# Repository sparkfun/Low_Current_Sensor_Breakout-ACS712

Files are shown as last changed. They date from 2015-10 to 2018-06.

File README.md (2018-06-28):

**NOTE:** *This product has been retired from our catalog. There is an updated drop-in replacement with the ACS723 available: [SEN-14544](https://github.com/sparkfun/Current_Sensor_Breakout-ACS723-Low_Current). If you are looking for more up-to-date info, please check out some of these resources to see how other users are still hacking and improving on this product version.*

* *[SparkFun Forum](https://forum.sparkfun.com/)*
* *[Comments Here on GitHub](https://github.com/sparkfun/Low_Current_Sensor_Breakout-ACS712/issues)*
* *[IRC Channel](https://www.sparkfun.com/news/263)*

SparkFun Low Current Sensor Breakout Board - ACS712
======================================================

SparkFun Low Current Sensor Breakout Board - ACS712

[*SparkFun Low Current Sensor Breakout Board - ACS712 (SEN-08883)*](https://www.sparkfun.com/products/8883) 

This current sensor gives precise current measurement for both AC and DC signals. 
These are good sensors for metering and measuring overall power consumption of systems.
The ACS712 Low Current Sensor Breakout outputs an analog voltage that varies linearly with sensed current.

Repository Contents
-------------------
* **/Hardware** - All Eagle design files (.brd, .sch)

Documentation
--------------
* **[Hookup Guide](https://learn.sparkfun.com/tutorials/acs712-low-current-sensor-hookup-guide)** - Basic hookup guide for the ACS712.

Product Versions
----------------

* [SEN-08883 (RETIRED)](https://www.sparkfun.com/products/8883)- Initial release; ACS712 Version of this Board

License Information
-------------------

This product is _**open source**_! 

Please review the LICENSE.md file for license information. 

If you have any questions or concerns on licensing, please contact techsupport@sparkfun.com.

Distributed as-is; no warranty is given.

- Your friends at SparkFun.

_<COLLABORATION CREDIT>_

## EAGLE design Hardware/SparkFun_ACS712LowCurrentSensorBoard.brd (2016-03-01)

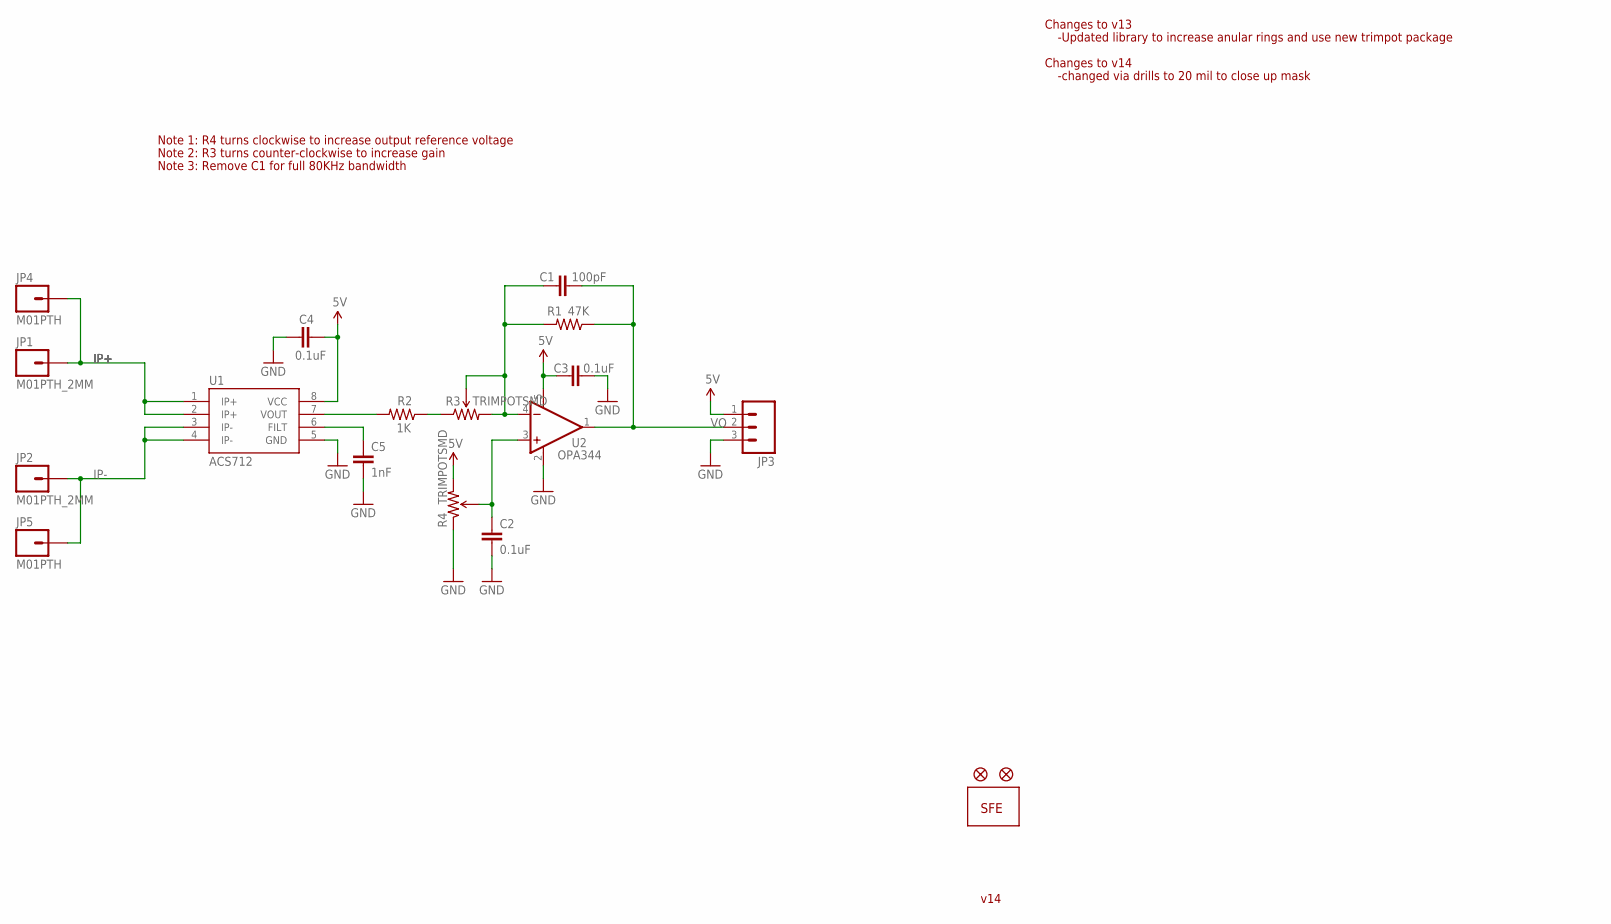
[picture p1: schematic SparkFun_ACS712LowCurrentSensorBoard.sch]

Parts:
C1: 100pF; 0402-CAP
C2, C3, C4: 0.1uF; 0402-CAP
C5: 1nF; 0402-CAP
JP1, JP2: M01PTH_2MM; 1X01_2MM
JP3: M03PTH; 1X03
JP4, JP5: M01PTH; 1X01
R1: 47K; 0402-RES
R2: 1K; 0402-RES
R3, R4: TRIMPOTSMD; TRIMPOT-3MM
U1: ACS712; SO08
U2: OPA344; SOT23-5
U$1, U$3: FIDUCIALUFIDUCIAL; MICRO-FIDUCIAL
U$2: LOGO-SFENEW; SFE-NEW-WEBLOGO

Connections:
5V: C3.1, C4.2, JP3.1, R4.3 (CW), U1.8 (VCC), U2.5 (V+)
GND: C2.2, C3.2, C4.1, C5.2, JP3.3, R4.1 (CCW), U1.5 (GND), U2.2 (V-)
IP+: JP1.1, JP4.1, U1.1 (IP+), U1.2 (IP+)
IP-: JP2.1, JP5.1, U1.3 (IP-), U1.4 (IP-)
unnamed: R2.2, U1.7 (VOUT)
unnamed: R2.1, R3.1 (CCW)
unnamed: C1.2, R1.2, R3.2 (WIPER), R3.3 (CW), U2.4 (-IN)
unnamed: C2.1, R4.2 (WIPER), U2.3 (+IN)
unnamed: C5.1, U1.6 (FILT)
VO: C1.1, JP3.2, R1.1, U2.1 (OUT)

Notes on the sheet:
Note 1: R4 turns clockwise to increase output reference voltage
Note 2: R3 turns counter-clockwise to increase gain
Note 3: Remove C1 for full 80KHz bandwidth
Changes to v13
-Updated library to increase anular rings and use new trimpot package
Changes to v14
-changed via drills to 20 mil to close up mask
v14

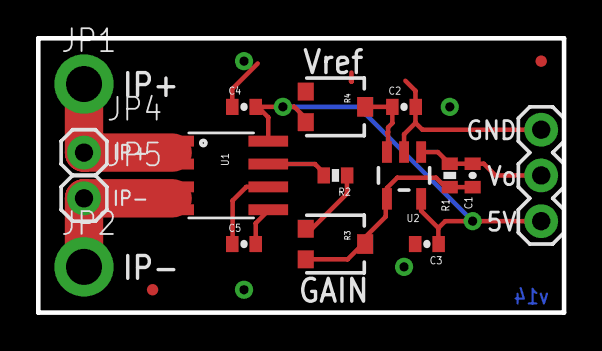
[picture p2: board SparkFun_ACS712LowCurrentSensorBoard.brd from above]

Board: 2 copper layers, 29.2 x 15.2 mm, 19 parts (1 on the bottom side), 10 nets.

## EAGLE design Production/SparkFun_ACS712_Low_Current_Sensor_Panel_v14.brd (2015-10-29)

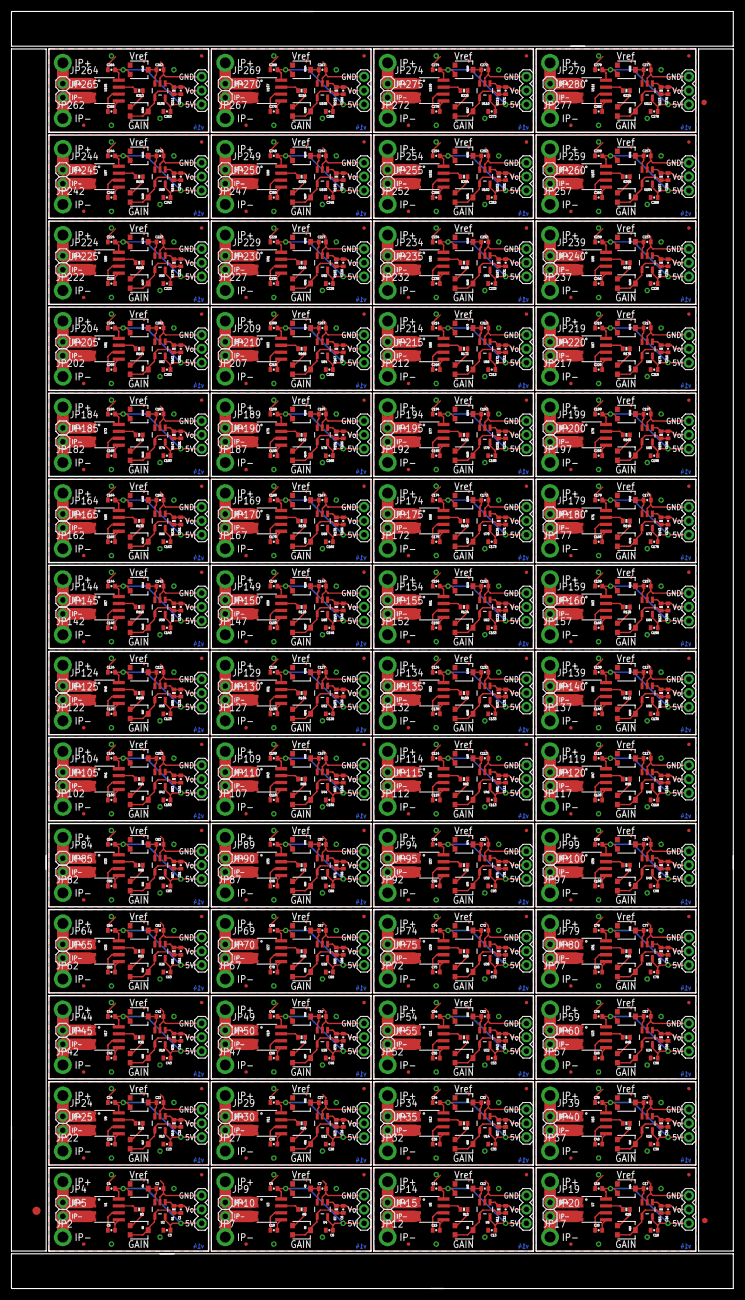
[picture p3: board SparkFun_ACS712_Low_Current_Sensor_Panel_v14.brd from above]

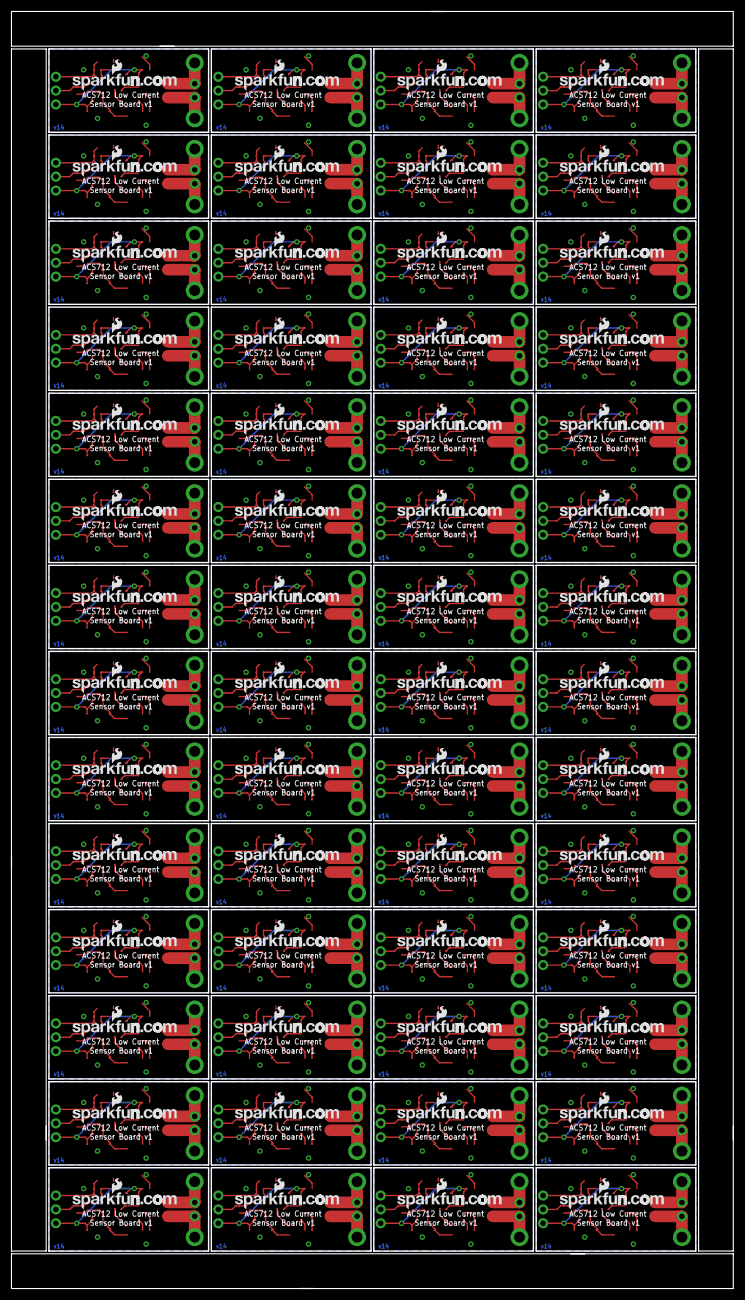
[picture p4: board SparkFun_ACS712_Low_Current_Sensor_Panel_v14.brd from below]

Board: 2 copper layers, 132.1 x 233.7 mm, 1067 parts (56 on the bottom side), 560 nets.

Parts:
C1, C2, C3, C4, C6, C7, C8, C9, C11, C12, C13, C14, C16, C17, C18, C19, C21, C22, C23, C24, C26, C27, C28, C29, C31, C32, C33, C34, C36, C37, C38, C39, C41, C42, C43, C44, C46, C47, C48, C49, C51, C52, C53, C54, C56, C57, C58, C59, C61, C62, C63, C64, C66, C67, C68, C69, C71, C72, C73, C74, C76, C77, C78, C79, C81, C82, C83, C84, C86, C87, C88, C89, C91, C92, C93, C94, C96, C97, C98, C99, C101, C102, C103, C104, C106, C107, C108, C109, C111, C112, C113, C114, C116, C117, C118, C119, C121, C122, C123, C124, C126, C127, C128, C129, C131, C132, C133, C134, C136, C137, C138, C139, C141, C142, C143, C144, C146, C147, C148, C149, C151, C152, C153, C154, C156, C157, C158, C159, C161, C162, C163, C164, C166, C167, C168, C169, C171, C172, C173, C174, C176, C177, C178, C179, C181, C182, C183, C184, C186, C187, C188, C189, C191, C192, C193, C194, C196, C197, C198, C199, C201, C202, C203, C204, C206, C207, C208, C209, C211, C212, C213, C214, C216, C217, C218, C219, C221, C222, C223, C224, C226, C227, C228, C229, C231, C232, C233, C234, C236, C237, C238, C239, C241, C242, C243, C244, C246, C247, C248, C249, C251, C252, C253, C254, C256, C257, C258, C259, C261, C262, C263, C264, C266, C267, C268, C269, C271, C272, C273, C274, C276, C277, C278, C279: 0.1uF; 0402-CAP
C5, C10, C15, C20, C25, C30, C35, C40, C45, C50, C55, C60, C65, C70, C75, C80, C85, C90, C95, C100, C105, C110, C115, C120, C125, C130, C135, C140, C145, C150, C155, C160, C165, C170, C175, C180, C185, C190, C195, C200, C205, C210, C215, C220, C225, C230, C235, C240, C245, C250, C255, C260, C265, C270, C275, C280: 1nF; 0402-CAP
E$1: FIDUCIAL-1.5X3
E$5, E$7: FIDUCIAL-1X2
JP1, JP2, JP6, JP7, JP11, JP12, JP16, JP17, JP21, JP22, JP26, JP27, JP31, JP32, JP36, JP37, JP41, JP42, JP46, JP47, JP51, JP52, JP56, JP57, JP61, JP62, JP66, JP67, JP71, JP72, JP76, JP77, JP81, JP82, JP86, JP87, JP91, JP92, JP96, JP97, JP101, JP102, JP106, JP107, JP111, JP112, JP116, JP117, JP121, JP122, JP126, JP127, JP131, JP132, JP136, JP137, JP141, JP142, JP146, JP147, JP151, JP152, JP156, JP157, JP161, JP162, JP166, JP167, JP171, JP172, JP176, JP177, JP181, JP182, JP186, JP187, JP191, JP192, JP196, JP197, JP201, JP202, JP206, JP207, JP211, JP212, JP216, JP217, JP221, JP222, JP226, JP227, JP231, JP232, JP236, JP237, JP241, JP242, JP246, JP247, JP251, JP252, JP256, JP257, JP261, JP262, JP266, JP267, JP271, JP272, JP276, JP277: M01PTH_2MM; 1X01_2MM
JP3, JP8, JP13, JP18, JP23, JP28, JP33, JP38, JP43, JP48, JP53, JP58, JP63, JP68, JP73, JP78, JP83, JP88, JP93, JP98, JP103, JP108, JP113, JP118, JP123, JP128, JP133, JP138, JP143, JP148, JP153, JP158, JP163, JP168, JP173, JP178, JP183, JP188, JP193, JP198, JP203, JP208, JP213, JP218, JP223, JP228, JP233, JP238, JP243, JP248, JP253, JP258, JP263, JP268, JP273, JP278: 1X03
JP4, JP5, JP9, JP10, JP14, JP15, JP19, JP20, JP24, JP25, JP29, JP30, JP34, JP35, JP39, JP40, JP44, JP45, JP49, JP50, JP54, JP55, JP59, JP60, JP64, JP65, JP69, JP70, JP74, JP75, JP79, JP80, JP84, JP85, JP89, JP90, JP94, JP95, JP99, JP100, JP104, JP105, JP109, JP110, JP114, JP115, JP119, JP120, JP124, JP125, JP129, JP130, JP134, JP135, JP139, JP140, JP144, JP145, JP149, JP150, JP154, JP155, JP159, JP160, JP164, JP165, JP169, JP170, JP174, JP175, JP179, JP180, JP184, JP185, JP189, JP190, JP194, JP195, JP199, JP200, JP204, JP205, JP209, JP210, JP214, JP215, JP219, JP220, JP224, JP225, JP229, JP230, JP234, JP235, JP239, JP240, JP244, JP245, JP249, JP250, JP254, JP255, JP259, JP260, JP264, JP265, JP269, JP270, JP274, JP275, JP279, JP280: M01PTH; 1X01
R1, R7, R11, R15, R19, R23, R27, R31, R35, R39, R43, R47, R51, R55, R59, R63, R67, R71, R75, R79, R83, R87, R91, R95, R99, R103, R107, R111, R115, R119, R123, R127, R131, R135, R139, R143, R147, R151, R155, R159, R163, R167, R171, R175, R179, R183, R187, R191, R195, R199, R203, R207, R211, R215, R219, R223: 47K; 0402-RES
R2, R8, R12, R16, R20, R24, R28, R32, R36, R40, R44, R48, R52, R56, R60, R64, R68, R72, R76, R80, R84, R88, R92, R96, R100, R104, R108, R112, R116, R120, R124, R128, R132, R136, R140, R144, R148, R152, R156, R160, R164, R168, R172, R176, R180, R184, R188, R192, R196, R200, R204, R208, R212, R216, R220, R224: 1K; 0402-RES
R3, R4, R5, R6, R9, R10, R13, R14, R17, R18, R21, R22, R25, R26, R29, R30, R33, R34, R37, R38, R41, R42, R45, R46, R49, R50, R53, R54, R57, R58, R61, R62, R65, R66, R69, R70, R73, R74, R77, R78, R81, R82, R85, R86, R89, R90, R93, R94, R97, R98, R101, R102, R105, R106, R109, R110, R113, R114, R117, R118, R121, R122, R125, R126, R129, R130, R133, R134, R137, R138, R141, R142, R145, R146, R149, R150, R153, R154, R157, R158, R161, R162, R165, R166, R169, R170, R173, R174, R177, R178, R181, R182, R185, R186, R189, R190, R193, R194, R197, R198, R201, R202, R205, R206, R209, R210, R213, R214, R217, R218, R221, R222: TRIMPOTSMD; TRIMPOT-3MM
U1, U3, U5, U7, U9, U11, U13, U15, U17, U19, U21, U23, U25, U27, U29, U31, U33, U35, U37, U39, U41, U43, U45, U47, U49, U51, U53, U55, U57, U59, U61, U63, U65, U67, U69, U71, U73, U75, U77, U79, U81, U83, U85, U87, U89, U91, U93, U95, U97, U99, U101, U103, U105, U107, U109, U111: ACS712; SO08
U2, U4, U6, U8, U10, U12, U14, U16, U18, U20, U22, U24, U26, U28, U30, U32, U34, U36, U38, U40, U42, U44, U46, U48, U50, U52, U54, U56, U58, U60, U62, U64, U66, U68, U70, U72, U74, U76, U78, U80, U82, U84, U86, U88, U90, U92, U94, U96, U98, U100, U102, U104, U106, U108, U110, U112: OPA344; SOT23-5
U$1, U$3, U$5, U$6, U$8, U$9, U$11, U$12, U$14, U$15, U$17, U$18, U$20, U$21, U$23, U$24, U$26, U$27, U$29, U$30, U$32, U$33, U$35, U$36, U$38, U$39, U$41, U$42, U$44, U$45, U$47, U$48, U$50, U$51, U$53, U$54, U$56, U$57, U$59, U$60, U$62, U$63, U$65, U$66, U$68, U$69, U$71, U$72, U$74, U$75, U$77, U$78, U$80, U$81, U$83, U$84, U$86, U$87, U$89, U$90, U$92, U$93, U$95, U$96, U$98, U$99, U$101, U$102, U$104, U$105, U$107, U$108, U$110, U$111, U$113, U$114, U$116, U$117, U$119, U$120, U$122, U$123, U$125, U$126, U$128, U$129, U$131, U$132, U$134, U$135, U$137, U$138, U$140, U$141, U$143, U$144, U$146, U$147, U$149, U$150, U$152, U$153, U$155, U$156, U$158, U$159, U$161, U$162, U$164, U$165, U$167, U$168: FIDUCIALUFIDUCIAL; MICRO-FIDUCIAL
U$2, U$4, U$7, U$10, U$13, U$16, U$19, U$22, U$25, U$28, U$31, U$34, U$37, U$40, U$43, U$46, U$49, U$52, U$55, U$58, U$61, U$64, U$67, U$70, U$73, U$76, U$79, U$82, U$85, U$88, U$91, U$94, U$97, U$100, U$103, U$106, U$109, U$112, U$115, U$118, U$121, U$124, U$127, U$130, U$133, U$136, U$139, U$142, U$145, U$148, U$151, U$154, U$157, U$160, U$163, U$166: LOGO-SFENEW; SFE-NEW-WEBLOGO

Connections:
5V: C3.1, C4.2, JP3.1, R4.3, U1.8, U2.5
5V1: C8.1, C9.2, JP8.1, R6.3, U3.8, U4.5
5V2: C13.1, C14.2, JP13.1, R10.3, U5.8, U6.5
5V3: C18.1, C19.2, JP18.1, R14.3, U7.8, U8.5
5V4: C23.1, C24.2, JP23.1, R18.3, U9.8, U10.5
5V5: C28.1, C29.2, JP28.1, R22.3, U11.8, U12.5
5V6: C33.1, C34.2, JP33.1, R26.3, U13.8, U14.5
5V7: C38.1, C39.2, JP38.1, R30.3, U15.8, U16.5
5V8: C43.1, C44.2, JP43.1, R34.3, U17.8, U18.5
5V9: C48.1, C49.2, JP48.1, R38.3, U19.8, U20.5
5V10: C53.1, C54.2, JP53.1, R42.3, U21.8, U22.5
5V11: C58.1, C59.2, JP58.1, R46.3, U23.8, U24.5
5V12: C63.1, C64.2, JP63.1, R50.3, U25.8, U26.5
5V13: C68.1, C69.2, JP68.1, R54.3, U27.8, U28.5
5V14: C73.1, C74.2, JP73.1, R58.3, U29.8, U30.5
5V15: C78.1, C79.2, JP78.1, R62.3, U31.8, U32.5
5V16: C83.1, C84.2, JP83.1, R66.3, U33.8, U34.5
5V17: C88.1, C89.2, JP88.1, R70.3, U35.8, U36.5
5V18: C93.1, C94.2, JP93.1, R74.3, U37.8, U38.5
5V19: C98.1, C99.2, JP98.1, R78.3, U39.8, U40.5
5V20: C103.1, C104.2, JP103.1, R82.3, U41.8, U42.5
5V21: C108.1, C109.2, JP108.1, R86.3, U43.8, U44.5
5V22: C113.1, C114.2, JP113.1, R90.3, U45.8, U46.5
5V23: C118.1, C119.2, JP118.1, R94.3, U47.8, U48.5
5V24: C123.1, C124.2, JP123.1, R98.3, U49.8, U50.5
5V25: C128.1, C129.2, JP128.1, R102.3, U51.8, U52.5
5V26: C133.1, C134.2, JP133.1, R106.3, U53.8, U54.5
5V27: C138.1, C139.2, JP138.1, R110.3, U55.8, U56.5
5V28: C143.1, C144.2, JP143.1, R114.3, U57.8, U58.5
5V29: C148.1, C149.2, JP148.1, R118.3, U59.8, U60.5
5V30: C153.1, C154.2, JP153.1, R122.3, U61.8, U62.5
5V31: C158.1, C159.2, JP158.1, R126.3, U63.8, U64.5
5V32: C163.1, C164.2, JP163.1, R130.3, U65.8, U66.5
5V33: C168.1, C169.2, JP168.1, R134.3, U67.8, U68.5
5V34: C173.1, C174.2, JP173.1, R138.3, U69.8, U70.5
5V35: C178.1, C179.2, JP178.1, R142.3, U71.8, U72.5
5V36: C183.1, C184.2, JP183.1, R146.3, U73.8, U74.5
5V37: C188.1, C189.2, JP188.1, R150.3, U75.8, U76.5
5V38: C193.1, C194.2, JP193.1, R154.3, U77.8, U78.5
5V39: C198.1, C199.2, JP198.1, R158.3, U79.8, U80.5
5V40: C203.1, C204.2, JP203.1, R162.3, U81.8, U82.5
5V41: C208.1, C209.2, JP208.1, R166.3, U83.8, U84.5
5V42: C213.1, C214.2, JP213.1, R170.3, U85.8, U86.5
5V43: C218.1, C219.2, JP218.1, R174.3, U87.8, U88.5
5V44: C223.1, C224.2, JP223.1, R178.3, U89.8, U90.5
5V45: C228.1, C229.2, JP228.1, R182.3, U91.8, U92.5
5V46: C233.1, C234.2, JP233.1, R186.3, U93.8, U94.5
5V47: C238.1, C239.2, JP238.1, R190.3, U95.8, U96.5
5V48: C243.1, C244.2, JP243.1, R194.3, U97.8, U98.5
5V49: C248.1, C249.2, JP248.1, R198.3, U99.8, U100.5
5V50: C253.1, C254.2, JP253.1, R202.3, U101.8, U102.5
5V51: C258.1, C259.2, JP258.1, R206.3, U103.8, U104.5
5V52: C263.1, C264.2, JP263.1, R210.3, U105.8, U106.5
5V53: C268.1, C269.2, JP268.1, R214.3, U107.8, U108.5
5V54: C273.1, C274.2, JP273.1, R218.3, U109.8, U110.5
5V55: C278.1, C279.2, JP278.1, R222.3, U111.8, U112.5
GND: C2.2, C3.2, C4.1, C5.2, JP3.3, R4.1, U1.5, U2.2
GND1: C7.2, C8.2, C9.1, C10.2, JP8.3, R6.1, U3.5, U4.2
GND2: C12.2, C13.2, C14.1, C15.2, JP13.3, R10.1, U5.5, U6.2
GND3: C17.2, C18.2, C19.1, C20.2, JP18.3, R14.1, U7.5, U8.2
GND4: C22.2, C23.2, C24.1, C25.2, JP23.3, R18.1, U9.5, U10.2
GND5: C27.2, C28.2, C29.1, C30.2, JP28.3, R22.1, U11.5, U12.2
GND6: C32.2, C33.2, C34.1, C35.2, JP33.3, R26.1, U13.5, U14.2
GND7: C37.2, C38.2, C39.1, C40.2, JP38.3, R30.1, U15.5, U16.2
GND8: C42.2, C43.2, C44.1, C45.2, JP43.3, R34.1, U17.5, U18.2
GND9: C47.2, C48.2, C49.1, C50.2, JP48.3, R38.1, U19.5, U20.2
GND10: C52.2, C53.2, C54.1, C55.2, JP53.3, R42.1, U21.5, U22.2
GND11: C57.2, C58.2, C59.1, C60.2, JP58.3, R46.1, U23.5, U24.2
GND12: C62.2, C63.2, C64.1, C65.2, JP63.3, R50.1, U25.5, U26.2
GND13: C67.2, C68.2, C69.1, C70.2, JP68.3, R54.1, U27.5, U28.2
GND14: C72.2, C73.2, C74.1, C75.2, JP73.3, R58.1, U29.5, U30.2
GND15: C77.2, C78.2, C79.1, C80.2, JP78.3, R62.1, U31.5, U32.2
GND16: C82.2, C83.2, C84.1, C85.2, JP83.3, R66.1, U33.5, U34.2
GND17: C87.2, C88.2, C89.1, C90.2, JP88.3, R70.1, U35.5, U36.2
GND18: C92.2, C93.2, C94.1, C95.2, JP93.3, R74.1, U37.5, U38.2
GND19: C97.2, C98.2, C99.1, C100.2, JP98.3, R78.1, U39.5, U40.2
GND20: C102.2, C103.2, C104.1, C105.2, JP103.3, R82.1, U41.5, U42.2
GND21: C107.2, C108.2, C109.1, C110.2, JP108.3, R86.1, U43.5, U44.2
GND22: C112.2, C113.2, C114.1, C115.2, JP113.3, R90.1, U45.5, U46.2
GND23: C117.2, C118.2, C119.1, C120.2, JP118.3, R94.1, U47.5, U48.2
GND24: C122.2, C123.2, C124.1, C125.2, JP123.3, R98.1, U49.5, U50.2
GND25: C127.2, C128.2, C129.1, C130.2, JP128.3, R102.1, U51.5, U52.2
GND26: C132.2, C133.2, C134.1, C135.2, JP133.3, R106.1, U53.5, U54.2
GND27: C137.2, C138.2, C139.1, C140.2, JP138.3, R110.1, U55.5, U56.2
GND28: C142.2, C143.2, C144.1, C145.2, JP143.3, R114.1, U57.5, U58.2
GND29: C147.2, C148.2, C149.1, C150.2, JP148.3, R118.1, U59.5, U60.2
GND30: C152.2, C153.2, C154.1, C155.2, JP153.3, R122.1, U61.5, U62.2
GND31: C157.2, C158.2, C159.1, C160.2, JP158.3, R126.1, U63.5, U64.2
GND32: C162.2, C163.2, C164.1, C165.2, JP163.3, R130.1, U65.5, U66.2
GND33: C167.2, C168.2, C169.1, C170.2, JP168.3, R134.1, U67.5, U68.2
GND34: C172.2, C173.2, C174.1, C175.2, JP173.3, R138.1, U69.5, U70.2
GND35: C177.2, C178.2, C179.1, C180.2, JP178.3, R142.1, U71.5, U72.2
GND36: C182.2, C183.2, C184.1, C185.2, JP183.3, R146.1, U73.5, U74.2
GND37: C187.2, C188.2, C189.1, C190.2, JP188.3, R150.1, U75.5, U76.2
GND38: C192.2, C193.2, C194.1, C195.2, JP193.3, R154.1, U77.5, U78.2
GND39: C197.2, C198.2, C199.1, C200.2, JP198.3, R158.1, U79.5, U80.2
GND40: C202.2, C203.2, C204.1, C205.2, JP203.3, R162.1, U81.5, U82.2
GND41: C207.2, C208.2, C209.1, C210.2, JP208.3, R166.1, U83.5, U84.2
GND42: C212.2, C213.2, C214.1, C215.2, JP213.3, R170.1, U85.5, U86.2
GND43: C217.2, C218.2, C219.1, C220.2, JP218.3, R174.1, U87.5, U88.2
GND44: C222.2, C223.2, C224.1, C225.2, JP223.3, R178.1, U89.5, U90.2
GND45: C227.2, C228.2, C229.1, C230.2, JP228.3, R182.1, U91.5, U92.2
GND46: C232.2, C233.2, C234.1, C235.2, JP233.3, R186.1, U93.5, U94.2
GND47: C237.2, C238.2, C239.1, C240.2, JP238.3, R190.1, U95.5, U96.2
GND48: C242.2, C243.2, C244.1, C245.2, JP243.3, R194.1, U97.5, U98.2
GND49: C247.2, C248.2, C249.1, C250.2, JP248.3, R198.1, U99.5, U100.2
GND50: C252.2, C253.2, C254.1, C255.2, JP253.3, R202.1, U101.5, U102.2
GND51: C257.2, C258.2, C259.1, C260.2, JP258.3, R206.1, U103.5, U104.2
GND52: C262.2, C263.2, C264.1, C265.2, JP263.3, R210.1, U105.5, U106.2
GND53: C267.2, C268.2, C269.1, C270.2, JP268.3, R214.1, U107.5, U108.2
GND54: C272.2, C273.2, C274.1, C275.2, JP273.3, R218.1, U109.5, U110.2
GND55: C277.2, C278.2, C279.1, C280.2, JP278.3, R222.1, U111.5, U112.2
IP+: JP1.1, JP4.1, U1.1, U1.2
IP+1: JP6.1, JP9.1, U3.1, U3.2
IP+2: JP11.1, JP14.1, U5.1, U5.2
IP+3: JP16.1, JP19.1, U7.1, U7.2
IP+4: JP21.1, JP24.1, U9.1, U9.2
IP+5: JP26.1, JP29.1, U11.1, U11.2
IP+6: JP31.1, JP34.1, U13.1, U13.2
IP+7: JP36.1, JP39.1, U15.1, U15.2
IP+8: JP41.1, JP44.1, U17.1, U17.2
IP+9: JP46.1, JP49.1, U19.1, U19.2
IP+10: JP51.1, JP54.1, U21.1, U21.2
IP+11: JP56.1, JP59.1, U23.1, U23.2
IP+12: JP61.1, JP64.1, U25.1, U25.2
IP+13: JP66.1, JP69.1, U27.1, U27.2
IP+14: JP71.1, JP74.1, U29.1, U29.2
IP+15: JP76.1, JP79.1, U31.1, U31.2
IP+16: JP81.1, JP84.1, U33.1, U33.2
IP+17: JP86.1, JP89.1, U35.1, U35.2
IP+18: JP91.1, JP94.1, U37.1, U37.2
IP+19: JP96.1, JP99.1, U39.1, U39.2
IP+20: JP101.1, JP104.1, U41.1, U41.2
IP+21: JP106.1, JP109.1, U43.1, U43.2
IP+22: JP111.1, JP114.1, U45.1, U45.2
IP+23: JP116.1, JP119.1, U47.1, U47.2
IP+24: JP121.1, JP124.1, U49.1, U49.2
IP+25: JP126.1, JP129.1, U51.1, U51.2
IP+26: JP131.1, JP134.1, U53.1, U53.2
IP+27: JP136.1, JP139.1, U55.1, U55.2
IP+28: JP141.1, JP144.1, U57.1, U57.2
IP+29: JP146.1, JP149.1, U59.1, U59.2
IP+30: JP151.1, JP154.1, U61.1, U61.2
IP+31: JP156.1, JP159.1, U63.1, U63.2
IP+32: JP161.1, JP164.1, U65.1, U65.2
IP+33: JP166.1, JP169.1, U67.1, U67.2
IP+34: JP171.1, JP174.1, U69.1, U69.2
IP+35: JP176.1, JP179.1, U71.1, U71.2
IP+36: JP181.1, JP184.1, U73.1, U73.2
IP+37: JP186.1, JP189.1, U75.1, U75.2
IP+38: JP191.1, JP194.1, U77.1, U77.2
IP+39: JP196.1, JP199.1, U79.1, U79.2
IP+40: JP201.1, JP204.1, U81.1, U81.2
IP+41: JP206.1, JP209.1, U83.1, U83.2
IP+42: JP211.1, JP214.1, U85.1, U85.2
IP+43: JP216.1, JP219.1, U87.1, U87.2
IP+44: JP221.1, JP224.1, U89.1, U89.2
IP+45: JP226.1, JP229.1, U91.1, U91.2
IP+46: JP231.1, JP234.1, U93.1, U93.2
IP+47: JP236.1, JP239.1, U95.1, U95.2
IP+48: JP241.1, JP244.1, U97.1, U97.2
IP+49: JP246.1, JP249.1, U99.1, U99.2
IP+50: JP251.1, JP254.1, U101.1, U101.2
IP+51: JP256.1, JP259.1, U103.1, U103.2
IP+52: JP261.1, JP264.1, U105.1, U105.2
IP+53: JP266.1, JP269.1, U107.1, U107.2
IP+54: JP271.1, JP274.1, U109.1, U109.2
IP+55: JP276.1, JP279.1, U111.1, U111.2
IP-: JP2.1, JP5.1, U1.3, U1.4
IP-1: JP7.1, JP10.1, U3.3, U3.4
IP-2: JP12.1, JP15.1, U5.3, U5.4
IP-3: JP17.1, JP20.1, U7.3, U7.4
IP-4: JP22.1, JP25.1, U9.3, U9.4
IP-5: JP27.1, JP30.1, U11.3, U11.4
IP-6: JP32.1, JP35.1, U13.3, U13.4
IP-7: JP37.1, JP40.1, U15.3, U15.4
IP-8: JP42.1, JP45.1, U17.3, U17.4
IP-9: JP47.1, JP50.1, U19.3, U19.4
IP-10: JP52.1, JP55.1, U21.3, U21.4
IP-11: JP57.1, JP60.1, U23.3, U23.4
IP-12: JP62.1, JP65.1, U25.3, U25.4
IP-13: JP67.1, JP70.1, U27.3, U27.4
IP-14: JP72.1, JP75.1, U29.3, U29.4
IP-15: JP77.1, JP80.1, U31.3, U31.4
IP-16: JP82.1, JP85.1, U33.3, U33.4
IP-17: JP87.1, JP90.1, U35.3, U35.4
IP-18: JP92.1, JP95.1, U37.3, U37.4
IP-19: JP97.1, JP100.1, U39.3, U39.4
IP-20: JP102.1, JP105.1, U41.3, U41.4
IP-21: JP107.1, JP110.1, U43.3, U43.4
IP-22: JP112.1, JP115.1, U45.3, U45.4
IP-23: JP117.1, JP120.1, U47.3, U47.4
IP-24: JP122.1, JP125.1, U49.3, U49.4
IP-25: JP127.1, JP130.1, U51.3, U51.4
IP-26: JP132.1, JP135.1, U53.3, U53.4
IP-27: JP137.1, JP140.1, U55.3, U55.4
IP-28: JP142.1, JP145.1, U57.3, U57.4
IP-29: JP147.1, JP150.1, U59.3, U59.4
IP-30: JP152.1, JP155.1, U61.3, U61.4
IP-31: JP157.1, JP160.1, U63.3, U63.4
IP-32: JP162.1, JP165.1, U65.3, U65.4
IP-33: JP167.1, JP170.1, U67.3, U67.4
IP-34: JP172.1, JP175.1, U69.3, U69.4
IP-35: JP177.1, JP180.1, U71.3, U71.4
IP-36: JP182.1, JP185.1, U73.3, U73.4
IP-37: JP187.1, JP190.1, U75.3, U75.4
IP-38: JP192.1, JP195.1, U77.3, U77.4
IP-39: JP197.1, JP200.1, U79.3, U79.4
IP-40: JP202.1, JP205.1, U81.3, U81.4
IP-41: JP207.1, JP210.1, U83.3, U83.4
IP-42: JP212.1, JP215.1, U85.3, U85.4
IP-43: JP217.1, JP220.1, U87.3, U87.4
IP-44: JP222.1, JP225.1, U89.3, U89.4
IP-45: JP227.1, JP230.1, U91.3, U91.4
IP-46: JP232.1, JP235.1, U93.3, U93.4
IP-47: JP237.1, JP240.1, U95.3, U95.4
IP-48: JP242.1, JP245.1, U97.3, U97.4
IP-49: JP247.1, JP250.1, U99.3, U99.4
IP-50: JP252.1, JP255.1, U101.3, U101.4
IP-51: JP257.1, JP260.1, U103.3, U103.4
IP-52: JP262.1, JP265.1, U105.3, U105.4
IP-53: JP267.1, JP270.1, U107.3, U107.4
IP-54: JP272.1, JP275.1, U109.3, U109.4
IP-55: JP277.1, JP280.1, U111.3, U111.4
unnamed: R8.2, U3.7
unnamed: R5.1, R8.1
unnamed: R2.2, U1.7
unnamed: R2.1, R3.1
unnamed: C1.2, R1.2, R3.2, R3.3, U2.4
unnamed: C2.1, R4.2, U2.3
unnamed: C6.2, R5.2, R5.3, R7.2, U4.4
unnamed: C5.1, U1.6
unnamed: C7.1, R6.2, U4.3
unnamed: C10.1, U3.6
unnamed: R12.2, U5.7
unnamed: R9.1, R12.1
unnamed: C11.2, R9.2, R9.3, R11.2, U6.4
unnamed: C12.1, R10.2, U6.3
unnamed: C15.1, U5.6
unnamed: R16.2, U7.7
unnamed: R13.1, R16.1
unnamed: C16.2, R13.2, R13.3, R15.2, U8.4
unnamed: C17.1, R14.2, U8.3
unnamed: C20.1, U7.6
unnamed: R20.2, U9.7
unnamed: R17.1, R20.1
unnamed: C21.2, R17.2, R17.3, R19.2, U10.4
unnamed: C22.1, R18.2, U10.3
unnamed: C25.1, U9.6
unnamed: R24.2, U11.7
unnamed: R21.1, R24.1
unnamed: C26.2, R21.2, R21.3, R23.2, U12.4
unnamed: C27.1, R22.2, U12.3
unnamed: C30.1, U11.6
unnamed: R28.2, U13.7
unnamed: R25.1, R28.1
unnamed: C31.2, R25.2, R25.3, R27.2, U14.4
unnamed: C32.1, R26.2, U14.3
unnamed: C35.1, U13.6
unnamed: R32.2, U15.7
unnamed: R29.1, R32.1
unnamed: C36.2, R29.2, R29.3, R31.2, U16.4
unnamed: C37.1, R30.2, U16.3
unnamed: C40.1, U15.6
unnamed: R36.2, U17.7
unnamed: R33.1, R36.1
unnamed: C41.2, R33.2, R33.3, R35.2, U18.4
unnamed: C42.1, R34.2, U18.3
unnamed: C45.1, U17.6
unnamed: R40.2, U19.7
unnamed: R37.1, R40.1
unnamed: C46.2, R37.2, R37.3, R39.2, U20.4
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

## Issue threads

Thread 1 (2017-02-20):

Product Schematic Typo

AGlass0fMilk, 2017-02-20:
In the schematic for the ACS712 breakout (PDF on product page) it says to "Remove C1 for full 80kHz bandwidth." I think this is incorrect and should be changed to say "Remove C5." That capacitor (C5) is on the bandwidth-limiting "Filter" pin of the ACS712.

bboyho, 2018-06-28:
Hi,

Sorry, I just noticed this comment. I agree since the "Filter" pin on the ACS712 is supposed to adjust the bandwidth.  I'll see what I can do about adjusting the Eagle files and updating the links. I'd also have to update the tutorial that you wrote [ [ACS712 Low Current Sensor Hookup Guide:Hardware Overview](https://learn.sparkfun.com/tutorials/acs712-low-current-sensor-hookup-guide#hardware-overview) ] since it references C1 as the capacitor to remove. I think somehow the labels were rearranged but the note was not updated to reflect the changes.

bboyho, 2018-07-05:
I checked with the original engineer that designed the board and it looks like the schematic should be correct. He was referring to the capacitor connected to the amplifier in the second stage that is limiting the bandwidth of the output from the ACS712 in the first stage. The ACS712 in the first stage was using the typical application circuit in the datasheet from what he can remember.

Closed 2018-07-05.

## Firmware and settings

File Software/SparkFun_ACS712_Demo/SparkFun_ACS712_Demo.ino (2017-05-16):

/*  SparkFun ACS712 Demo
    Created by George Beckstein for SparkFun
    4/30/2017

    Uses an Arduino to set up the ACS712 Current Sensor
    See the product page at: https://www.sparkfun.com/products/8883

    Parts you may need:
    - 100 Ohm, 1/2W or greater resistor OR two 220 Ohm 1/4 resistors in parallel
    - ACS712 Breakout with on-board amplifier

    Optional equipment:
    - Oscilloscope
    - Multimeter (or two)
    - A power supply with current limiting/constant current would be handy to calibrate the device without using resistors
*/

const int analogInPin = A0;

// Number of samples to average the reading over
// Change this to make the reading smoother... but beware of buffer overflows!
const int avgSamples = 10;

int sensorValue = 0;

float sensitivity = 100.0 / 500.0; //100mA per 500mV = 0.2
float Vref = 2500; // Output voltage with no current: ~ 2500mV or 2.5V

void setup() {
  // initialize serial communications at 9600 bps:
  Serial.begin(9600);
}

void loop() {
  // read the analog in value:
  for (int i = 0; i < avgSamples; i++)
  {
    sensorValue += analogRead(analogInPin);

    // wait 2 milliseconds before the next loop
    // for the analog-to-digital converter to settle
    // after the last reading:
    delay(2);

  }

  sensorValue = sensorValue / avgSamples;

  // The on-board ADC is 10-bits -> 2^10 = 1024 -> 5V / 1024 ~= 4.88mV
  // The voltage is in millivolts
  float voltage = 4.88 * sensorValue;

  // This will calculate the actual current (in mA)
  // Using the Vref and sensitivity settings you configure
  float current = (voltage - Vref) * sensitivity;

  // This is the raw sensor value, not very useful without some calculations
  //Serial.print(sensorValue);

  /*************************************************************************************
   * Step 1.)
   * Uncomment and run the following code to set up the baseline voltage 
   * (the voltage with 0 current flowing through the device).
   * Make sure no current is flowing through the IP+ and IP- terminals during this part!
   * 
   * The output units are in millivolts. Use the Arduino IDE's Tools->Serial Plotter
   * To see a plot of the output. Adjust the Vref potentiometer to set the reference
   * voltage. This allows the sensor to output positive and negative currents!
   *************************************************************************************/
  
  Serial.print(voltage);
  //Serial.print("mV");

  /*************************************************************************************
   * Step 2.)
   * Keep running the same code as above to set up the sensitivity
   * (how many millivolts are output per Amp of current.
   * 
   * This time, use a known load current (measure this with a multimeter)
   * to give a constant output voltage. Adjust the sensitivity by turning the
   * gain potentiometer.
   * 
   * The sensitivity will be (Vreading - Vref)/(known current).
   *************************************************************************************/

    /*************************************************************************************
   * Step 3.)
   * Comment out the code used for the last two parts and uncomment the following code.
   * When you have performed the calibration steps above, make sure to change the 
   * global variables "sensitivity" and "Vref" to what you have set up.
   * 
   * This next line of code will print out the calculated current from these parameters.
   * The output is in mA
   *************************************************************************************/
  
  //Serial.print(current);
  //Serial.print("mA");


  // -- DO NOT UNCOMMENT BELOW THIS LINE --
  Serial.print("\n");

  // Reset the sensor value for the next reading
  sensorValue = 0;
}

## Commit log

2015-03-03 Adding hardware files, updating README
    [SparkFun_ACS712LowCurrentSensorBoardv14.brd, SparkFun_ACS712LowCurrentSensorBoardv14.sch]
2015-10-29 created new v14 panel
    [SparkFun_ACS712_Low_Current_Sensor_Panel_v14.brd]
2016-03-01 Updating to proper 100pF cap on C1, removing version number from file names
    [SparkFun_ACS712LowCurrentSensorBoardv14.brd, SparkFun_ACS712LowCurrentSensorBoardv14.sch]
2016-03-01 Fixing file names
    [SparkFun_ACS712LowCurrentSensorBoard.brd, SparkFun_ACS712LowCurrentSensorBoard.sch]
2017-05-16 Adding Arduino example sketch
    George Beckstein created example sketch for this part along with a
    hookup guide. Adding software folder with sketch.

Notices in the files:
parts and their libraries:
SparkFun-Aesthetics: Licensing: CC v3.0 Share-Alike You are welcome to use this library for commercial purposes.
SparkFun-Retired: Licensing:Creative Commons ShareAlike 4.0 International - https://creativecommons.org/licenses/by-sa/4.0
